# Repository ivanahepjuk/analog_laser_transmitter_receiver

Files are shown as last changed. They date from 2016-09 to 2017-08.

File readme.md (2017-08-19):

Laser transmitter and receiver, version 2.0

!!! Please consider, that using the laser beam is dangerus and wearing protective tools is required !!!

This schematics and PCB was designed and created by me and I am ok with using this resources for your own educational purposes.
If you decide to build it and use it in public, you can use my credentials as a resource, of course,)

Created August 2016 ivanahepjuk@gmail.com

DATA:

There are project folders created by PCB tool Kicad 4.0.4, but I dont think it will work once you download it and open in Kicad 
(because Kicad has terrible library management). Therefore I created another folder with pdf document with schematics, 
pcb boards and I also included the .svg file in case you want to manually tune the boards a bit using for example inscape.
Enjoy

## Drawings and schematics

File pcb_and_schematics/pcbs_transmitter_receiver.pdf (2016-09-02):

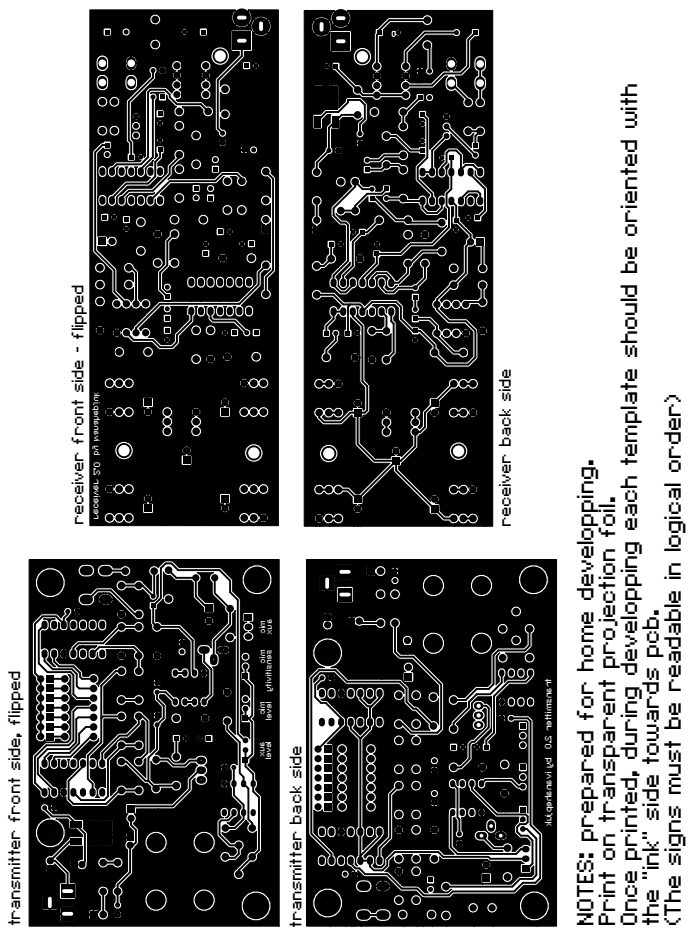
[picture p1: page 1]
mic mic; sensitivity aux; mic; level; aux level

Once printed, during developping each template should be oriented with

receiver front side - flipped

receiver back side

by ivanahepjuk receiver 2.0

(The signs must be readable in logical order)

NOTES: prepared for home developping.

Print on transparent projection foil.

the "ink" side towards pcb.

transmitter front side, flipped

transmitter 2.0 by ivanahepjuk

transmitter back side

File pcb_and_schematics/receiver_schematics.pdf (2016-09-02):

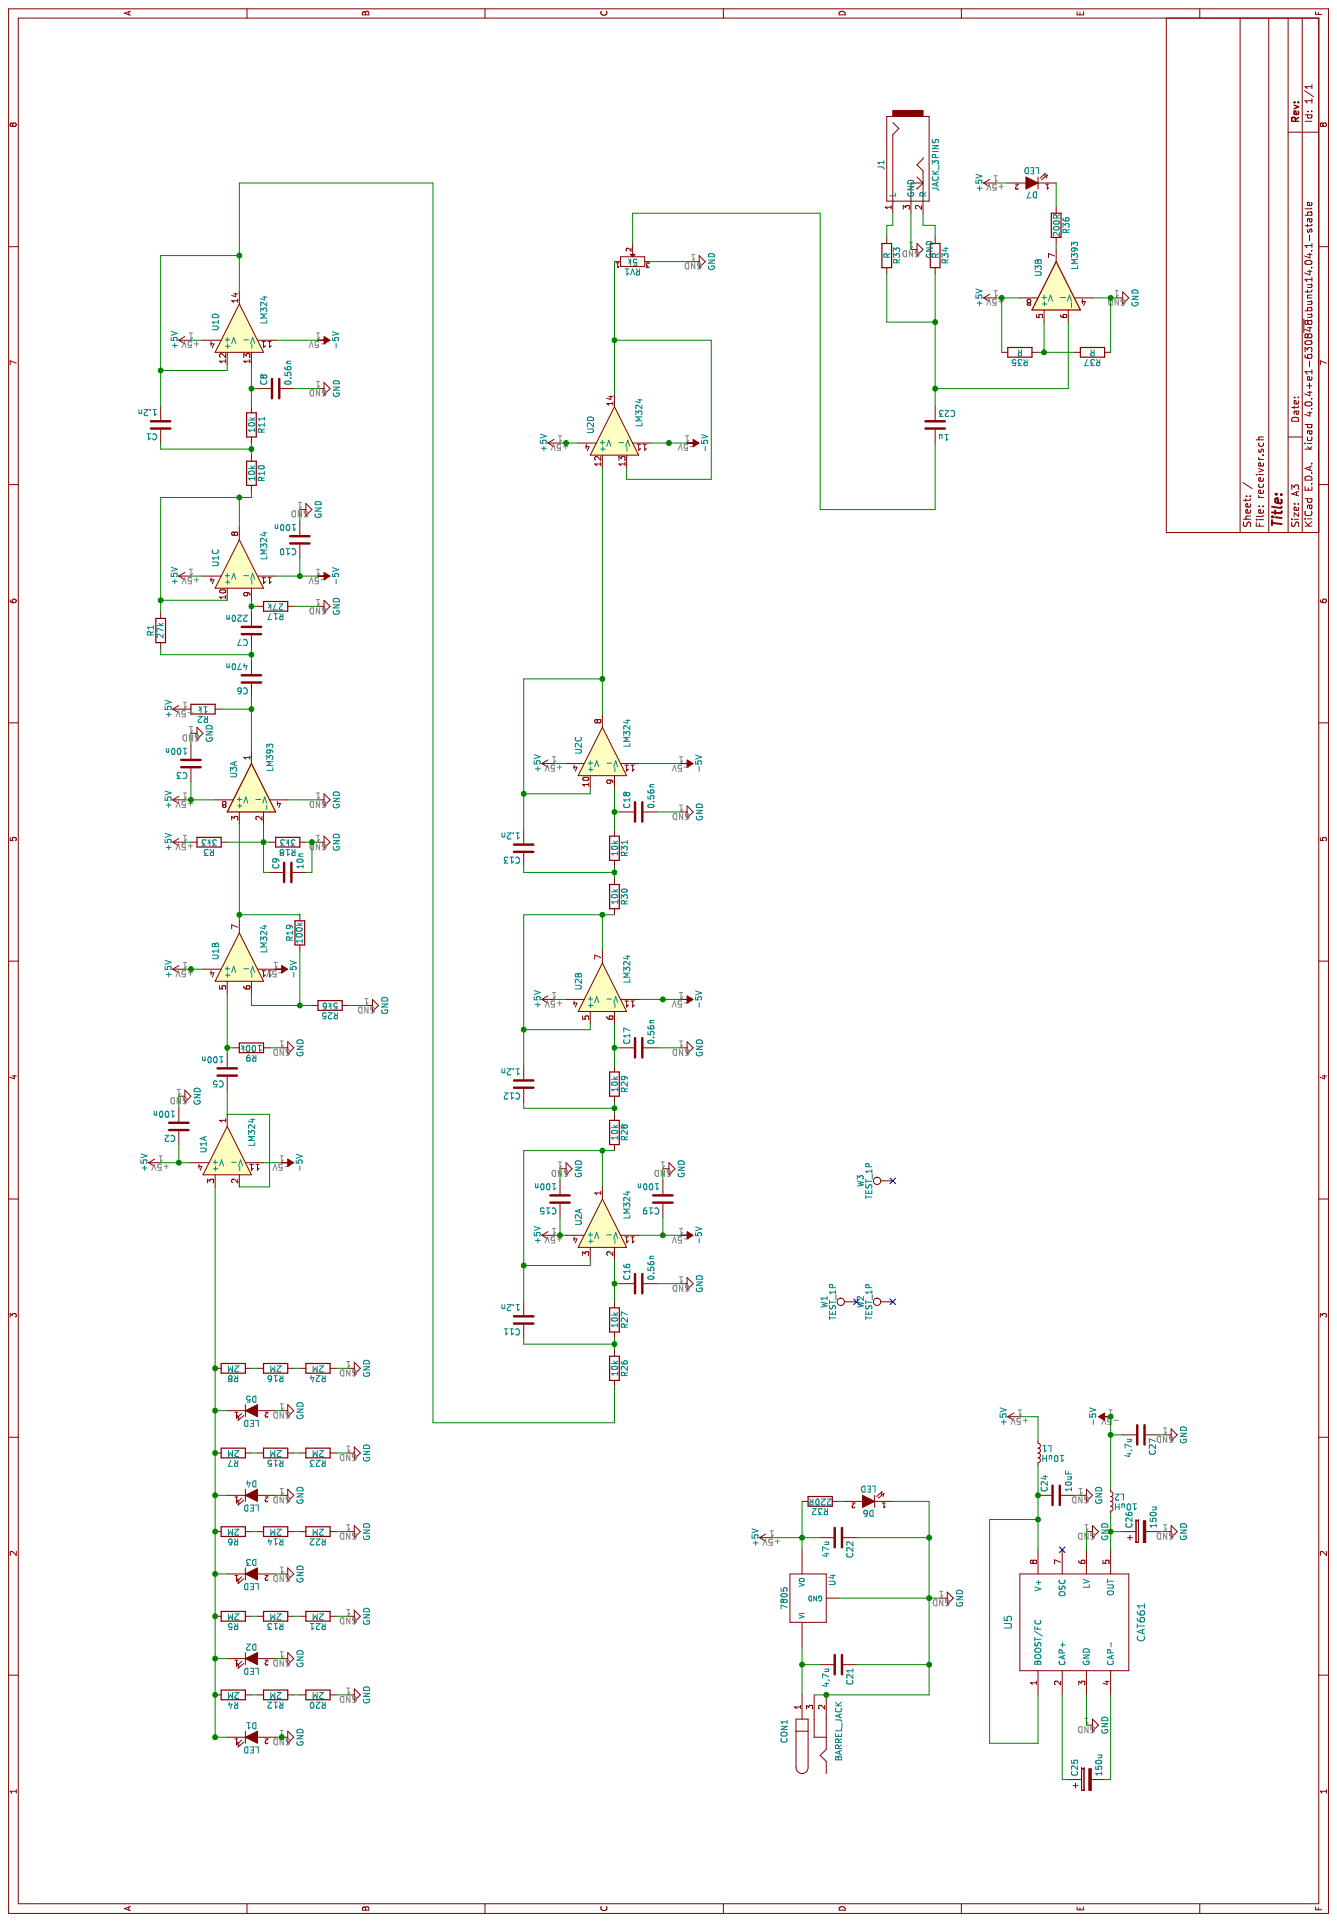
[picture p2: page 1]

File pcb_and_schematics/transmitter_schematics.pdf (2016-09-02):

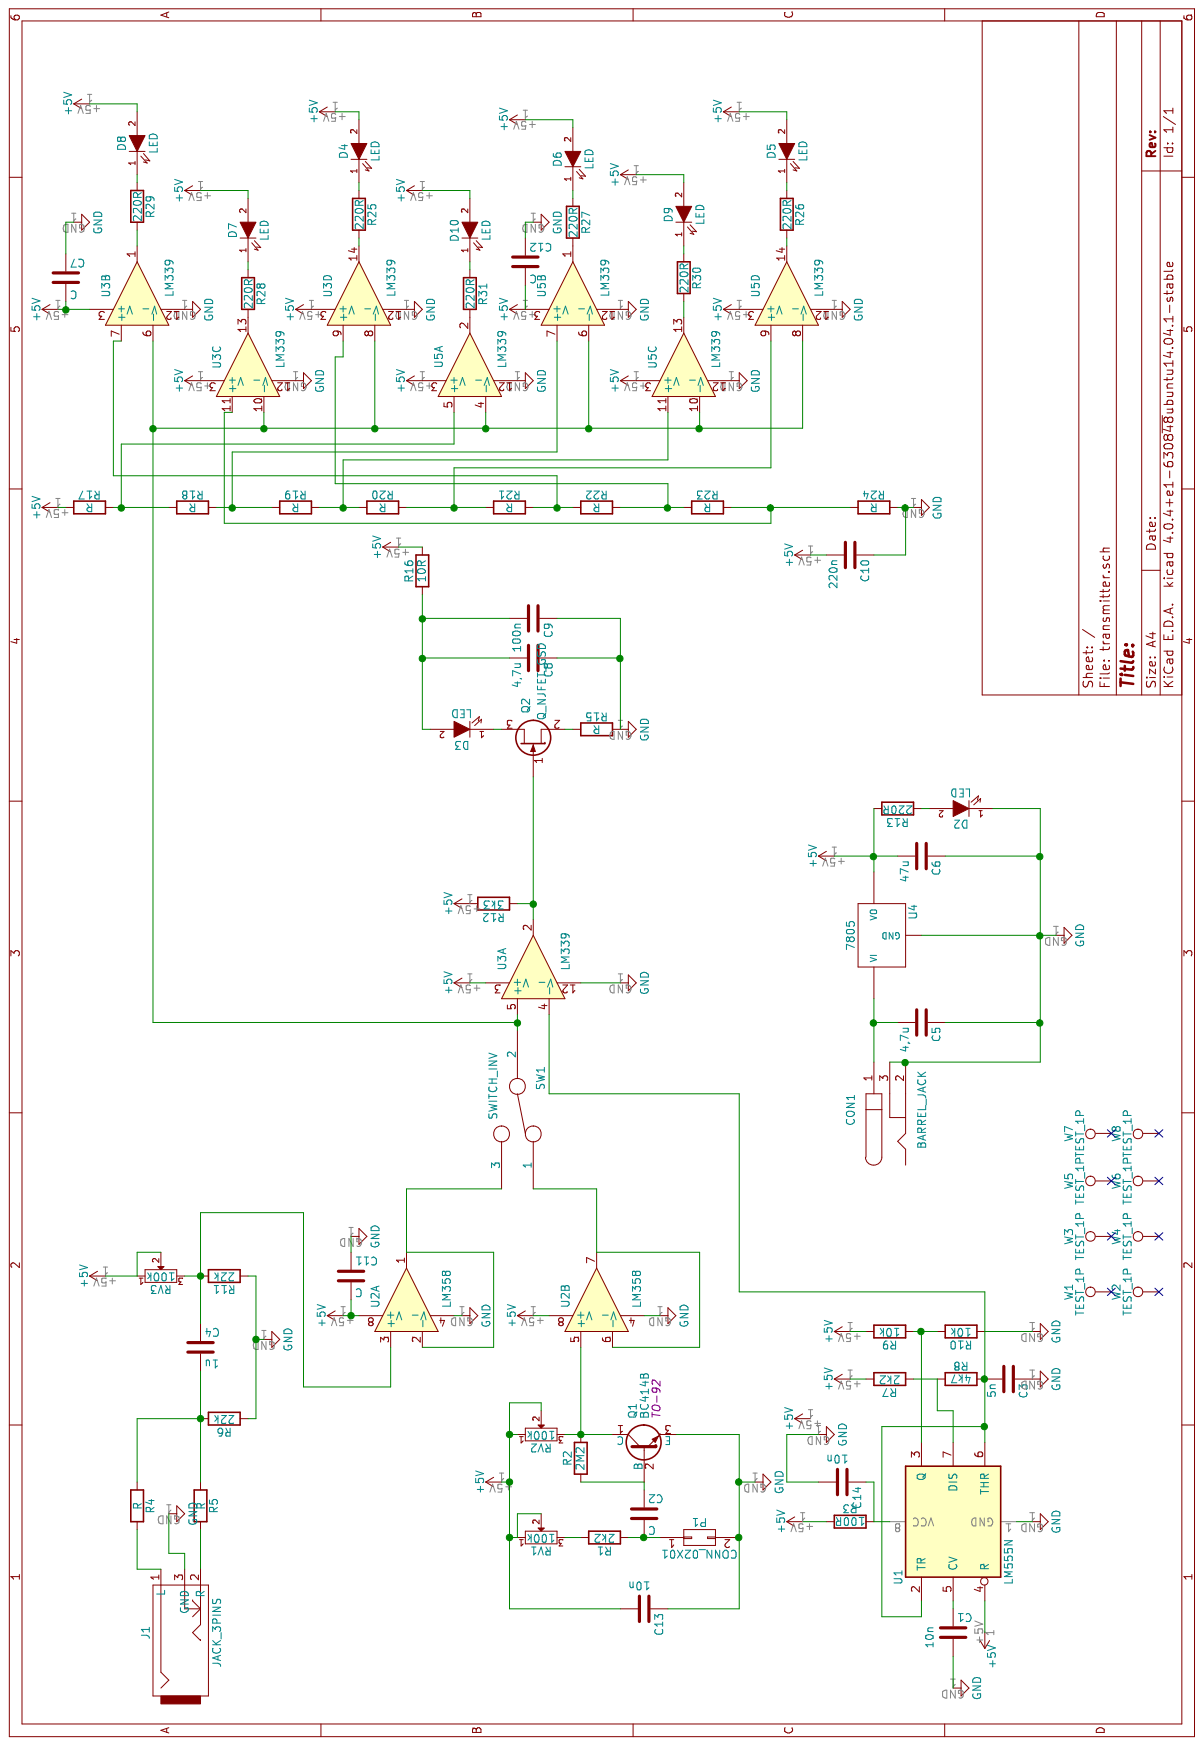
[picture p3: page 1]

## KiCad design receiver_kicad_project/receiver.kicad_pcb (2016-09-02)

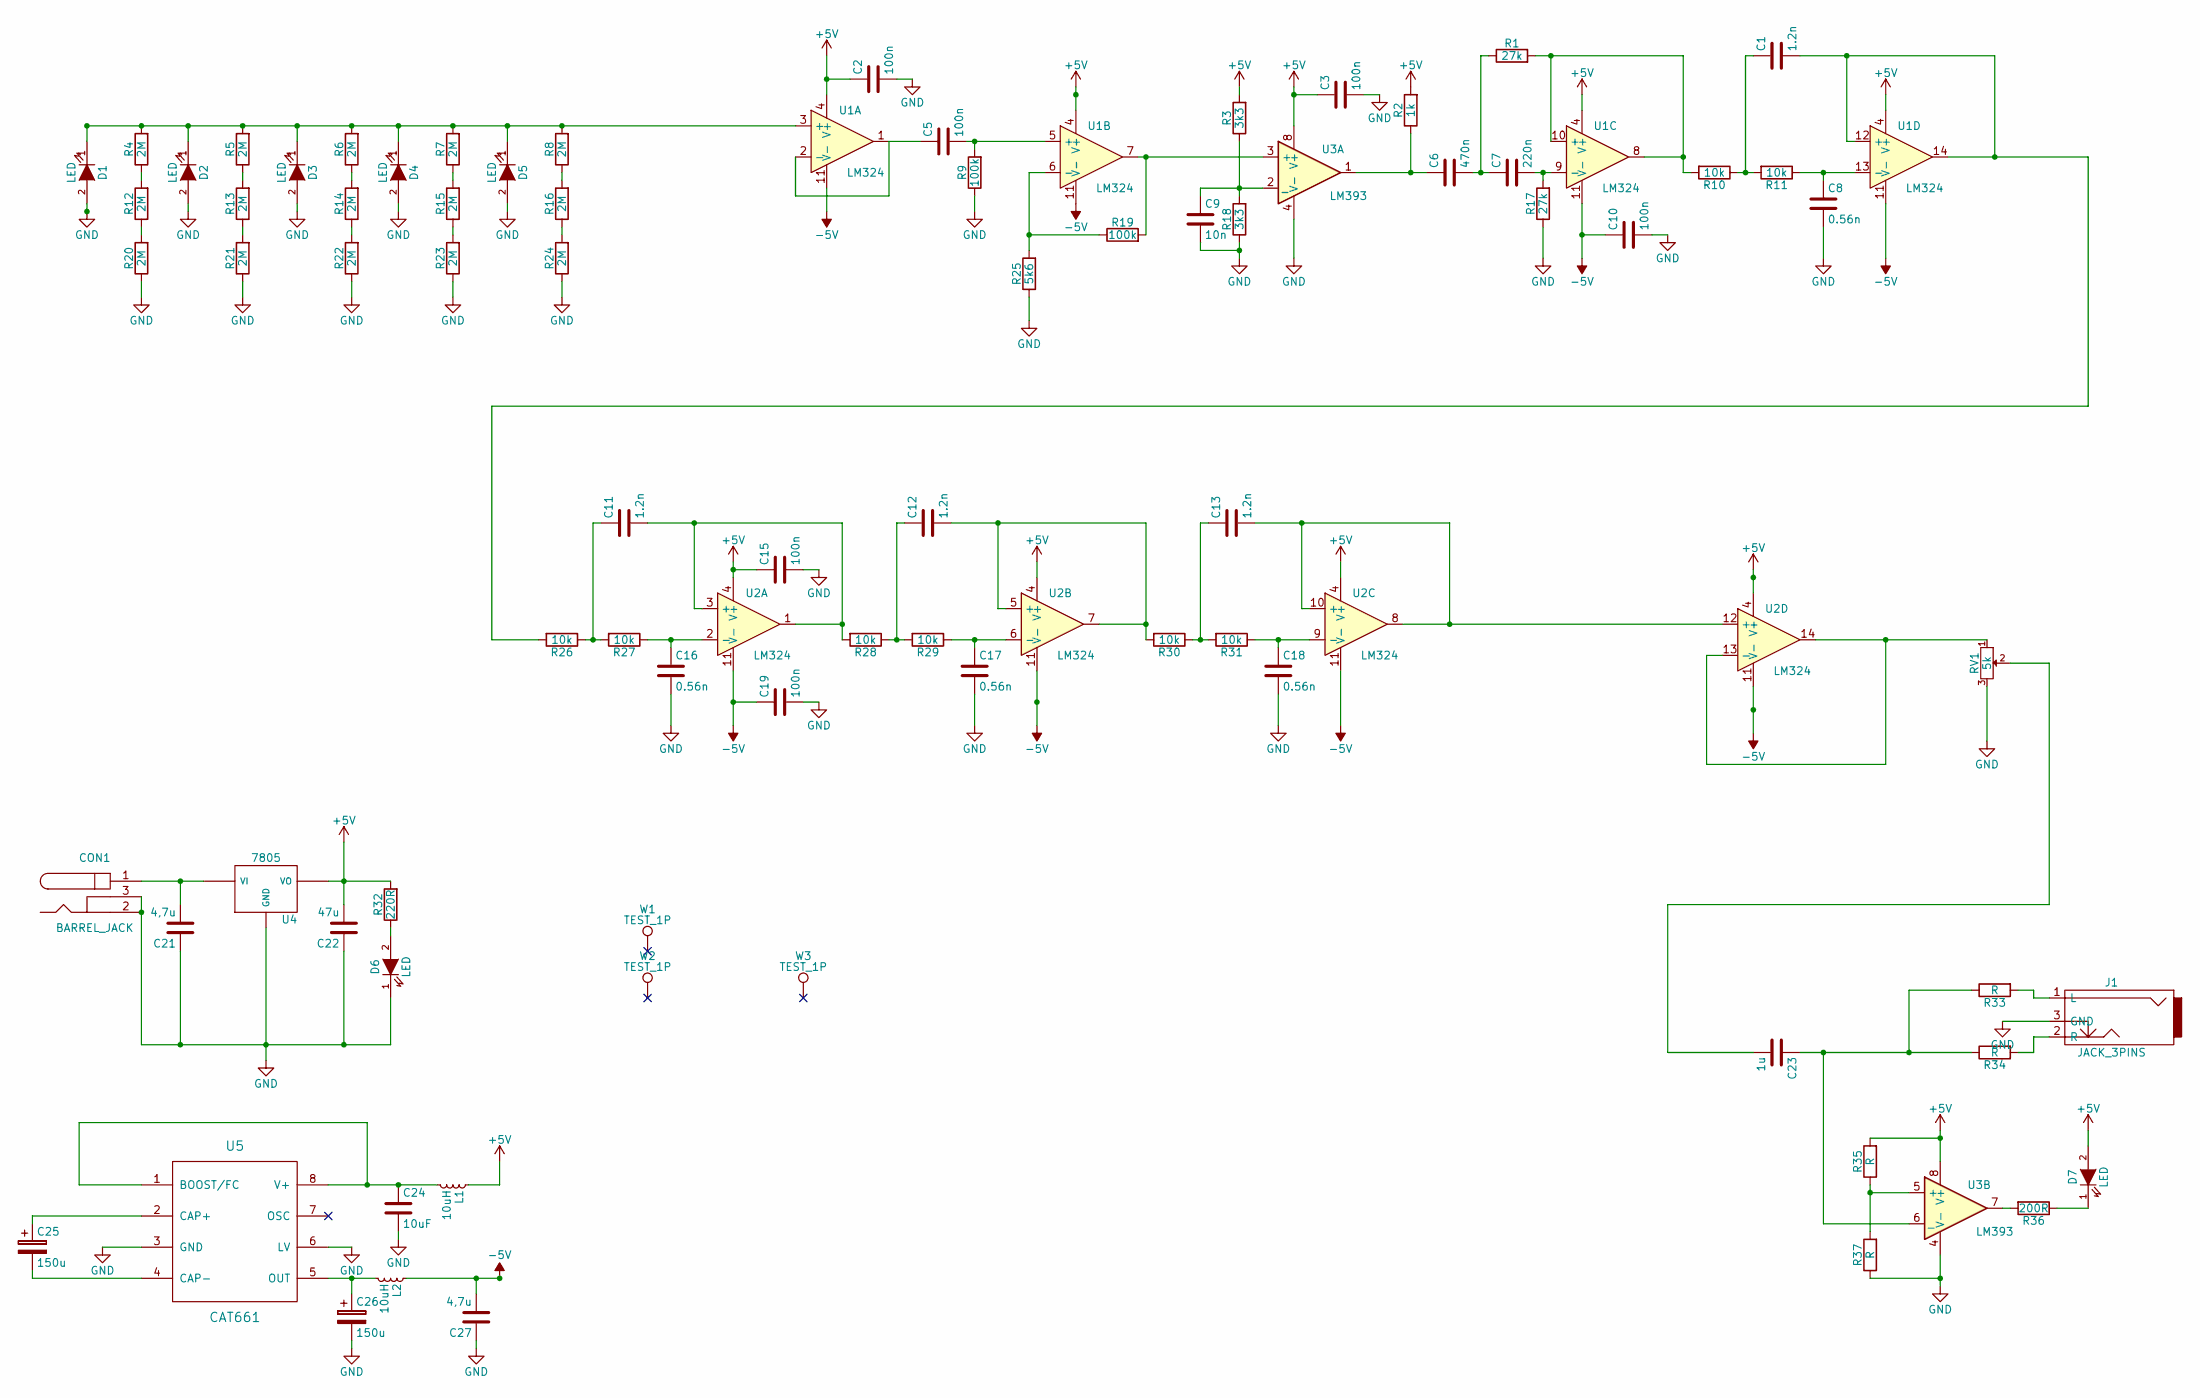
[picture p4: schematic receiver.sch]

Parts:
C1, C11, C12, C13: 1.2n; C_Disc_D3_P2.5
C2, C3, C5, C10, C15, C19: 100n; C_Disc_D3_P2.5
C6: 470n; C_Disc_D3_P2.5
C7: 220n; C_Disc_D3_P2.5
C8, C16, C17, C18: 0.56n; C_Disc_D3_P2.5
C9: 10n; C_Disc_D3_P2.5
C21: 4,7u; C_Radial_D5_L11_P2.5
C22: 47u; C_Radial_D5_L11_P2.5
C23: 1u; C_Radial_D5_L11_P2.5
C24: 10uF; C_Radial_D5_L11_P2.5
C25, C26: 150u; C_Radial_D10_L13_P5
C27: 4,7u; C_Radial_D5_L6_P2.5
CON1: BARREL_JACK; JACK_ALIM
D1, D2, D3, D4, D5, D6, D7: LED; LED-5MM
J1: JACK_3PINS; jack_3.5mm_3pins
L1, L2: 10uH; Choke_Toroid_horizontal_Diameter3-5mm_Amidon-T12
R1, R17: 27k; Resistor_Horizontal_RM7mm
R2: 1k; Resistor_Horizontal_RM7mm
R3, R18: 3k3; Resistor_Horizontal_RM7mm
R4, R5, R6, R7, R8, R12, R13, R14, R15, R16, R20, R21, R22, R23, R24: 2M; Resistor_Horizontal_RM7mm
R9, R19: 100k; Resistor_Horizontal_RM7mm
R10, R11, R26, R27, R28, R29, R30, R31: 10k; Resistor_Horizontal_RM7mm
R25: 5k6; Resistor_Horizontal_RM7mm
R32: 220R; Resistor_Horizontal_RM7mm
R33, R34, R35, R37: R; Resistor_Horizontal_RM7mm
R36: 200R; Resistor_Horizontal_RM7mm
RV1: 5k; Potentiometer_Bourns_3296W_3-8Zoll_Inline_ScrewUp
U1, U2: LM324; DIP-14_W7.62mm_LongPads
U3: LM393; PDIP-8
U4: 7805; TO-252-2Lead
U5: CAT661; PDIP-8
W1, W2, W3: TEST_1P; Pin_Header_Straight_1x01

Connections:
+5V: C2.1, C3.1, C15.1, C22.2, D7.2 (A), L1.1, R2.2, R3.2, R32.2, R35.2, U1.4 (V+), U2.4 (V+), U3.8 (V+), U4.3 (VO)
-5V: C10.1, C19.1, C27.2, L2.1, U1.11 (V-), U2.11 (V-)
GND: C2.2, C3.2, C8.2, C9.2, C10.2, C15.2, C16.2, C17.2, C18.2, C19.2, C21.1, C22.1, C24.2, C26.2, C27.1, CON1.2, CON1.3, D1.2 (A), D2.2 (A), D3.2 (A), D4.2 (A), D5.2 (A), D6.1 (K), J1.3 (GND), R9.1, R17.1, R18.1, R20.1, R21.1, R22.1, R23.1, R24.1, R25.1, R37.1, RV1.3, U3.4 (V-), U4.2 (GND), U5.3 (GND), U5.6 (LV)
unnamed: C1.1, R10.1, R11.2
unnamed: C1.2, R26.2, U1.12 (+), U1.14
unnamed: C5.1, U1.1, U1.2 (-)
unnamed: C5.2, R9.2, U1.5 (+)
unnamed: C6.1, R2.1, U3.1
unnamed: C6.2, C7.1, R1.1
unnamed: C7.2, R17.2, U1.9 (-)
unnamed: C8.1, R11.1, U1.13 (-)
unnamed: C9.1, R3.1, R18.2, U3.2 (_)
unnamed: C11.1, R26.1, R27.2
unnamed: C11.2, R28.2, U2.1, U2.3 (+)
unnamed: C12.1, R28.1, R29.2
unnamed: C12.2, R30.2, U2.5 (+), U2.7
unnamed: C13.1, R30.1, R31.2
unnamed: C13.2, U2.8, U2.10 (+), U2.12 (+)
unnamed: C16.1, R27.1, U2.2 (-)
unnamed: C17.1, R29.1, U2.6 (-)
unnamed: C18.1, R31.1, U2.9 (-)
unnamed: C21.2, CON1.1, U4.1 (VI)
unnamed: C23.1, R33.1, R34.1, U3.6 (_)
unnamed: C23.2, RV1.2
unnamed: C24.1, L1.2, U5.1 (BOOST/FC), U5.8 (V+)
unnamed: C25.1, U5.2 (CAP+)
unnamed: C25.2, U5.4 (CAP-)
unnamed: C26.1, L2.2, U5.5 (OUT)
unnamed: D1.1 (K), D2.1 (K), D3.1 (K), D4.1 (K), D5.1 (K), R4.2, R5.2, R6.2, R7.2, R8.2, U1.3 (+)
unnamed: D6.2 (A), R32.1
unnamed: D7.1 (K), R36.1
unnamed: J1.1 (L), R33.2
unnamed: J1.2 (R), R34.2
unnamed: R1.2, R10.2, U1.8, U1.10 (+)
unnamed: R12.1, R20.2
unnamed: R4.1, R12.2
unnamed: R13.1, R21.2
unnamed: R5.1, R13.2
unnamed: R14.1, R22.2
unnamed: R6.1, R14.2
unnamed: R15.1, R23.2
unnamed: R7.1, R15.2
unnamed: R16.1, R24.2
unnamed: R8.1, R16.2
unnamed: R19.1, R25.2, U1.6 (-)
unnamed: R19.2, U1.7, U3.3 (+)
unnamed: R35.1, R37.2, U3.5 (+)
unnamed: R36.2, U3.7
unnamed: RV1.1, U2.13 (-), U2.14

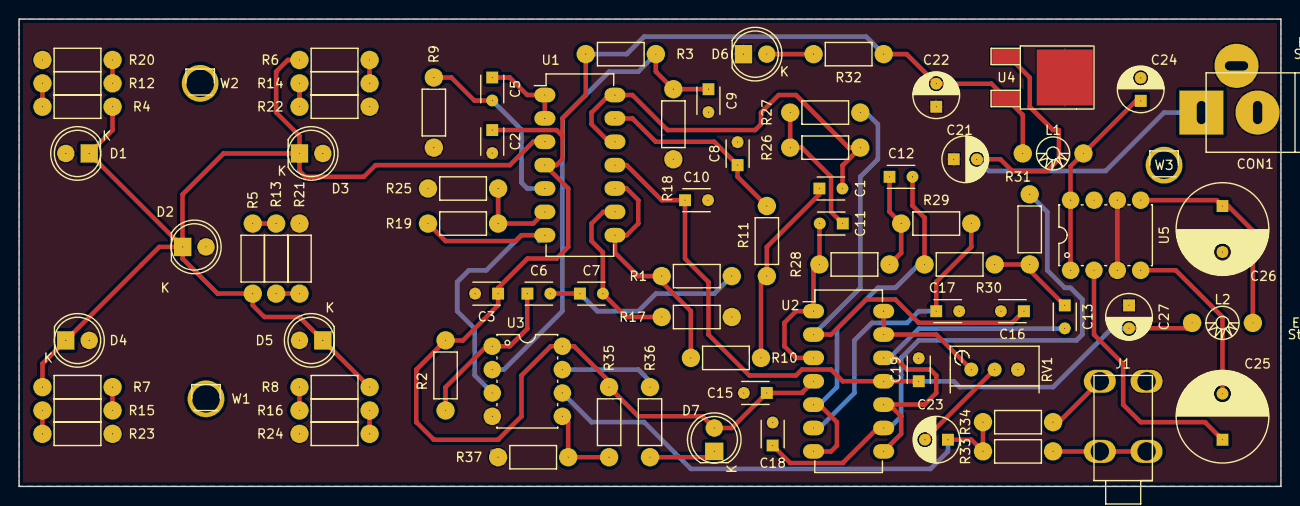
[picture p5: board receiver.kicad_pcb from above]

Board: 2 copper layers, 137.2 x 50.8 mm, 81 parts (0 on the bottom side), 49 nets.

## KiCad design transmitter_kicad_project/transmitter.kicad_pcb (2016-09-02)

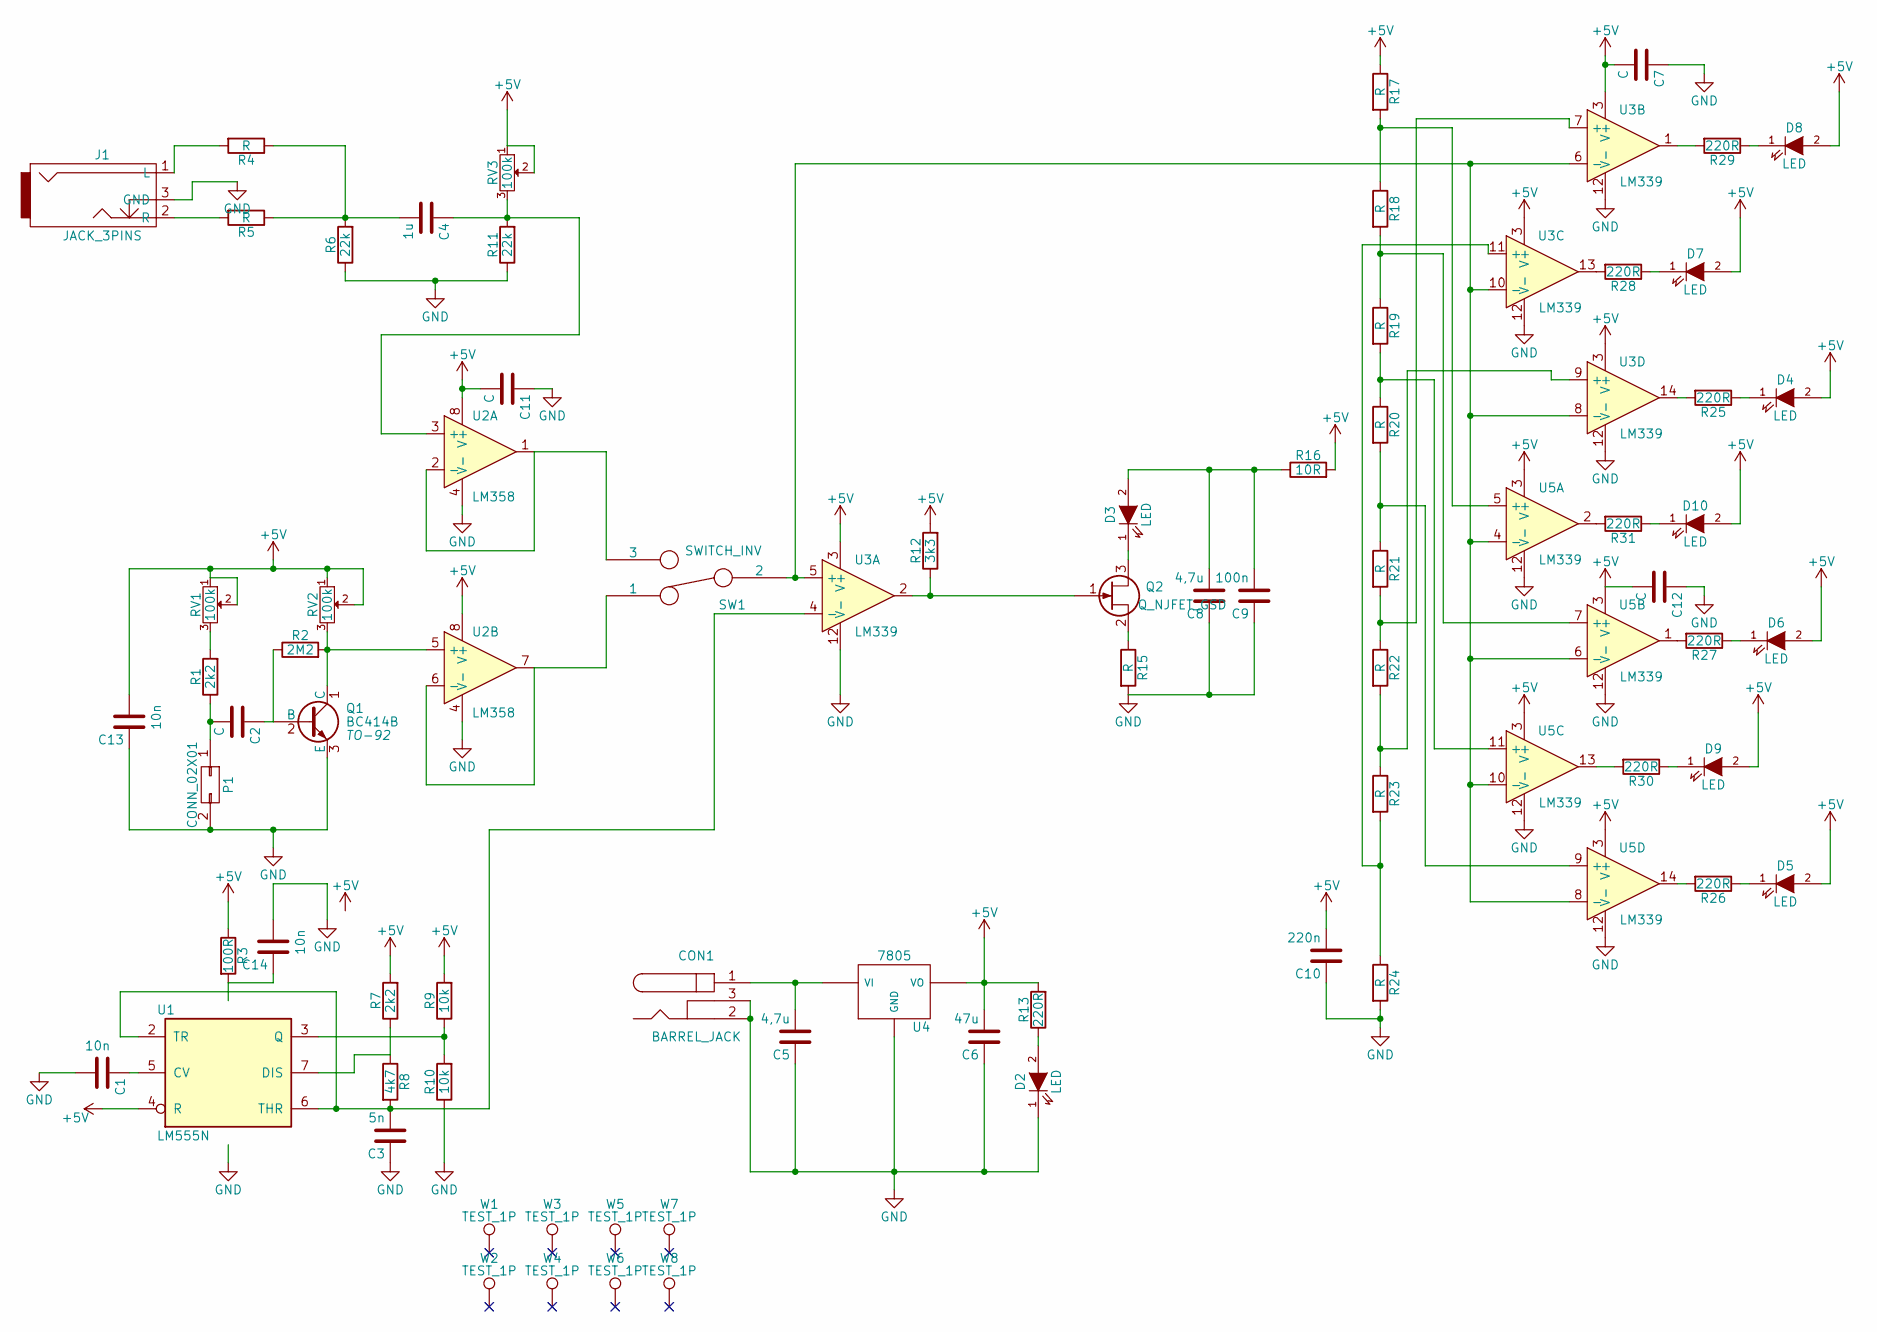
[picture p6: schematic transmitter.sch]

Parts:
C1, C13, C14: 10n; C_Disc_D3_P2.5
C2: C; C_Disc_D7.5_P5
C3: 5n; C_Disc_D3_P2.5
C4: 1u; C_Disc_D3_P2.5
C5, C8: 4,7u; C_Radial_D5_L11_P2
C6: 47u; C_Radial_D5_L11_P2
C7, C11, C12: C; C_Disc_D3_P2.5
C9: 100n; C_Disc_D3_P2.5
C10: 220n; C_Disc_D3_P2.5
CON1: BARREL_JACK
D2: LED; LED-3MM
D3, D4, D5, D6, D7, D8, D9, D10: LED; LED-5MM
J1: JACK_3PINS; jack_3.5mm_3pins
P1: CONN_02X01; C_Radial_D8_L11.5_P3.5
Q1: BC414B; TO-92
Q2: Q_NJFET_GSD; TO-220_Neutral123_Vertical_LargePads
R1, R7: 2k2; Resistor_Horizontal_RM7mm
R2: 2M2; Resistor_Horizontal_RM7mm
R3: 100R; Resistor_Horizontal_RM7mm
R4, R5, R15, R17, R18, R19, R20, R21, R22, R23, R24: R; Resistor_Horizontal_RM7mm
R6, R11: 22k; Resistor_Horizontal_RM7mm
R8: 4k7; Resistor_Horizontal_RM7mm
R9, R10: 10k; Resistor_Horizontal_RM7mm
R12: 3k3; Resistor_Horizontal_RM7mm
R13, R25, R26, R27, R28, R29, R30, R31: 220R; Resistor_Horizontal_RM7mm
R16: 10R; Resistor_Horizontal_RM7mm
RV1, RV2, RV3: 100k; Potentiometer_Trimmer-Suntan-TSR-3386C
SW1: SWITCH_INV; Pin_Header_Straight_1x03
U1: LM555N; PDIP-8
U2: LM358; PDIP-8
U3, U5: LM339; DIP-14_W7.62mm_LongPads
U4: 7805; TO-252-2Lead
W1, W2, W3, W4, W5, W6, W7, W8: TEST_1P; Pin_Header_Straight_1x01

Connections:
+5V: C6.2, C7.2, C10.2, C11.2, C12.2, C13.2, D4.2 (A), D5.2 (A), D6.2 (A), D7.2 (A), D8.2 (A), D9.2 (A), D10.2 (A), R3.1, R7.2, R9.2, R12.2, R13.2, R16.2, R17.1, RV1.1, RV1.2, RV2.1, RV2.2, RV3.1, RV3.2, U1.4 (R), U2.8 (V+), U3.3 (V+), U4.3 (VO), U5.3 (V+)
GND: C1.2, C3.1, C5.1, C6.1, C7.1, C8.1, C9.1, C10.1, C11.1, C12.1, C13.1, C14.2, CON1.2, CON1.3, D2.1 (K), J1.3 (GND), P1.2, Q1.3 (E), R6.1, R10.1, R11.1, R15.2, R24.2, U1.1 (GND), U2.4 (V-), U3.12 (V-), U4.2 (GND), U5.12 (V-)
unnamed: C1.1, U1.5 (CV)
unnamed: C2.1, Q1.2 (B), R2.1
unnamed: C2.2, P1.1, R1.1
unnamed: C3.2, R8.2, U1.2 (TR), U1.6 (THR), U3.4 (-)
unnamed: C4.1, R11.2, RV3.3, U2.3 (+)
unnamed: C4.2, R4.1, R5.1, R6.2
unnamed: C5.2, CON1.1, U4.1 (VI)
unnamed: C8.2, C9.2, D3.2 (A), R16.1
unnamed: D2.2 (A), R13.1
unnamed: D4.1 (K), R25.1
unnamed: D5.1 (K), R26.1
unnamed: D6.1 (K), R27.1
unnamed: D7.1 (K), R28.1
unnamed: D8.1 (K), R29.1
unnamed: D9.1 (K), R30.1
unnamed: D10.1 (K), R31.1
unnamed: J1.1 (L), R4.2
unnamed: J1.2 (R), R5.2
unnamed: Q1.1 (C), R2.2, RV2.3, U2.5 (+)
unnamed: Q2.1 (G), R12.1, U3.2
unnamed: R1.2, RV1.3
unnamed: R7.1, R8.1, U1.7 (DIS)
unnamed: R9.1, R10.2, U1.3 (Q)
unnamed: R17.2, R18.1, U5.5 (+)
unnamed: R18.2, R19.1, U5.7 (+)
unnamed: R19.2, R20.1, U5.11 (+)
unnamed: R20.2, R21.1, U5.9 (+)
unnamed: R21.2, R22.1, U3.7 (+)
unnamed: R22.2, R23.1, U3.9 (+)
unnamed: R23.2, R24.1, U3.11 (+)
unnamed: R25.2, U3.14
unnamed: R26.2, U5.14
unnamed: R27.2, U5.1
unnamed: R28.2, U3.13
unnamed: R29.2, U3.1
unnamed: R30.2, U5.13
unnamed: R31.2, U5.2
unnamed: SW1.1, U2.6 (-), U2.7
unnamed: SW1.2, U3.5 (+), U3.6 (-), U3.8 (-), U3.10 (-), U5.4 (-), U5.6 (-), U5.8 (-), U5.10 (-)
unnamed: SW1.3, U2.1, U2.2 (-)
VCC: C14.1, R3.2, U1.8 (VCC)

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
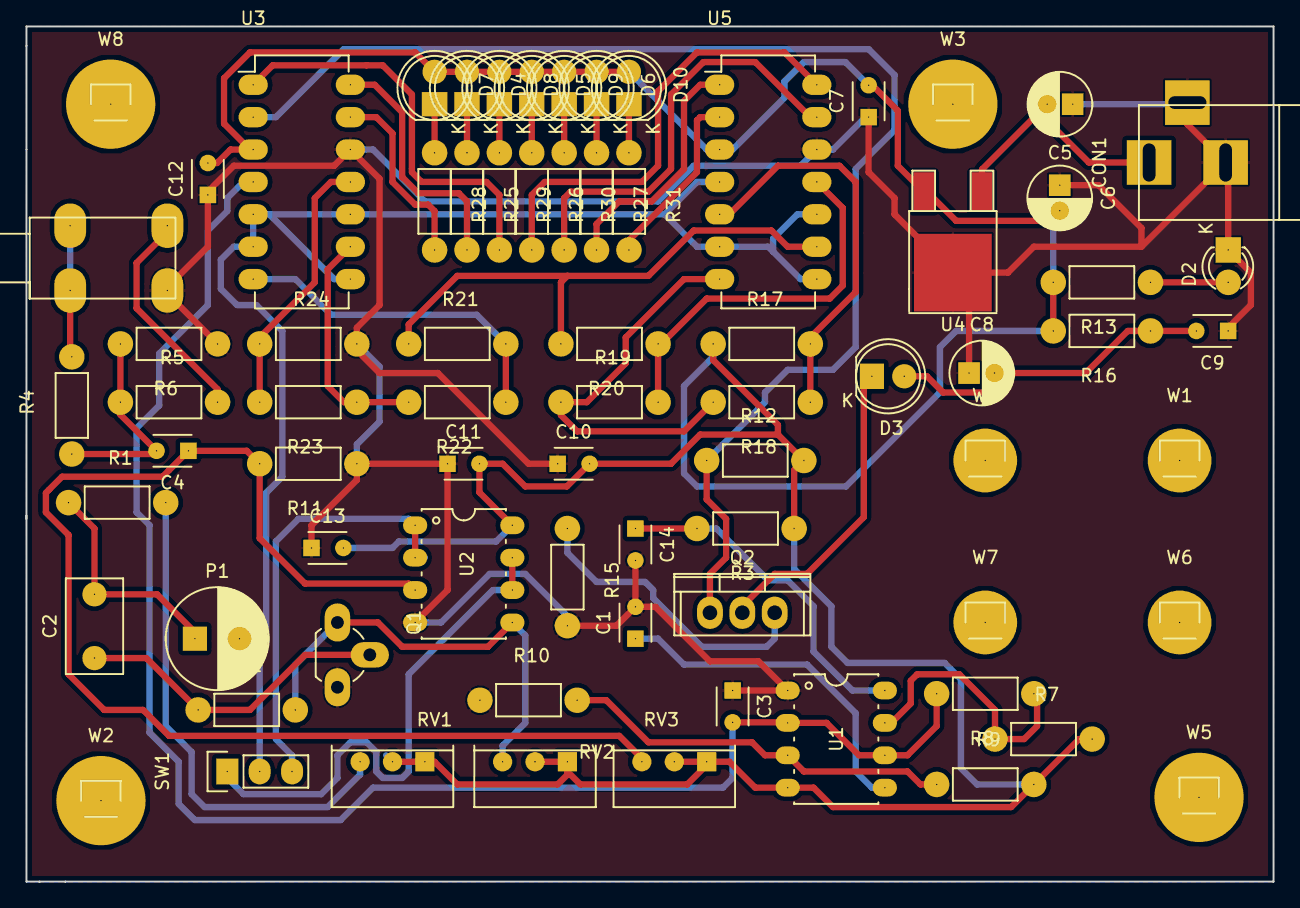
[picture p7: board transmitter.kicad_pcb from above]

Board: 2 copper layers, 97.8 x 67.1 mm, 75 parts (0 on the bottom side), 45 nets.
